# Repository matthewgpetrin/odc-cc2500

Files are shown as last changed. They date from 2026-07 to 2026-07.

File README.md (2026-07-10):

Copyright © 2026 Matthew Petrin

Liscenses are annoying. Please feel free to use this design for any personal projects. Please do not sell any products using this design without my express permission. And of course, follow any local RF regulations.

---
<kbd> 
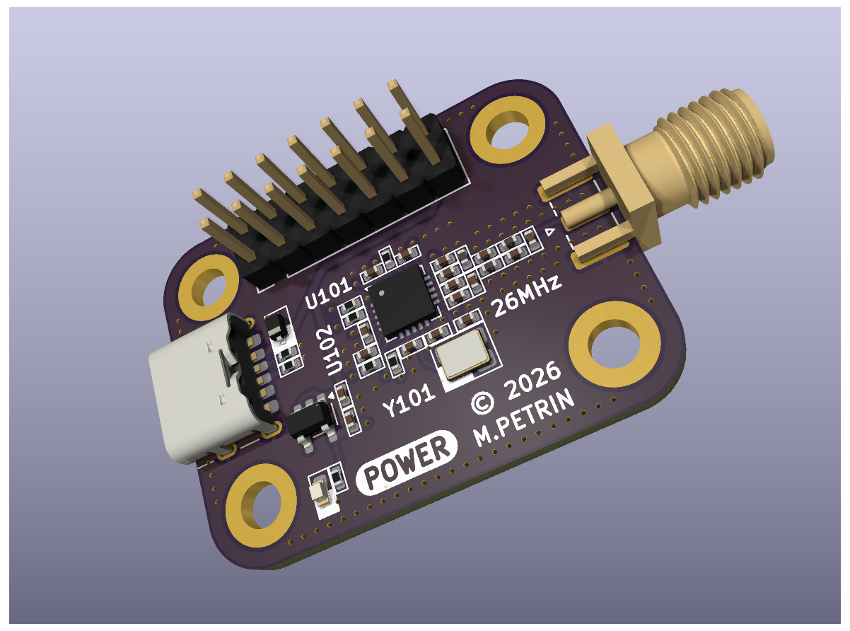
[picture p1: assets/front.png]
	 
</kbd>

---
<kbd> 
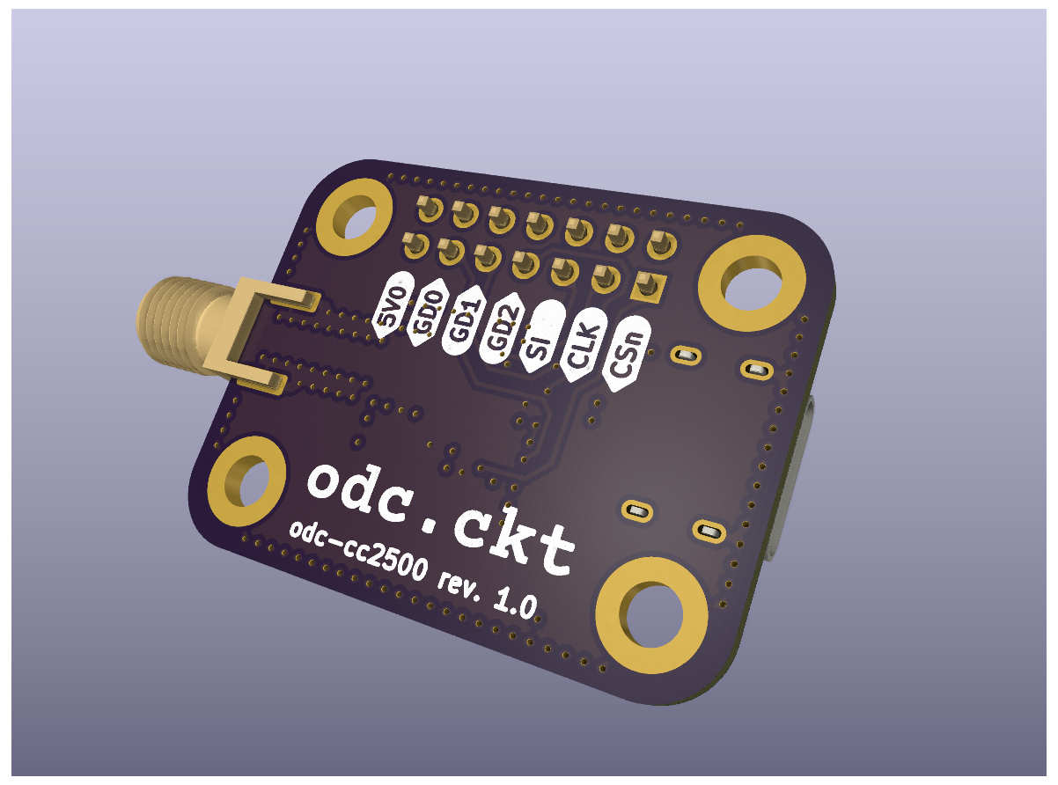
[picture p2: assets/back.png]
	 
</kbd>

## About:
This repo contains KiCAD files and fabrication outputs for a simple breakout board designed around the CC2500 transceiver. The board features a 0.1" pitch header providing access to the IC's control pins, and an SMA header on the RF output.

The board is to be powered by a 5V DC source, which is regulated down to 3.3V. Power can be provided via the rectangular header, or via USB C.

The project is designed in KiCAD 9, and should be compatible with equal or greater versions. All required symbols and footprints are contained within.

## Part Selection:
A BOM is provided in the repo. There are a few components which may be affected by manufacturing processes:

The choice of termination capacitors around the crystal resonator will depend on board parasitics - see the CC2500 datasheet for further details

The choice of current-limiting resistor on the power LED will obviously depend on the forward voltage of the selected LED and the desired brightness.

The series termination resistors on the CC2500 may need to be adjusted/shorted depending on bus impedance, bus length, edge rate, and external capacitance.

## Directories:
`assets`: Images associated with documentation.

`docs`: Currently empty. May be updated in the future.

`fab`: Files required for board fabrication and assembly (bill-of-materials, gerbers, schematics, and position files).

`kicad`: KiCAD project files, including schematic, layout, symbols, footprints, and design rules.

## Other Notes:
Board mounting holes are compatible with m3 or 4-40 screws, and are spaced 26x18 mm.

As of rev. 1.0, the mounting holes are not grounded.

## Datasheets:
[CC2500](https://www.ti.com/lit/ds/symlink/cc2500.pdf?ts=1783648273403&)

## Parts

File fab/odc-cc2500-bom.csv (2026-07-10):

Reference | Qty | Value | Manufacturer | Mfr. PN | Digikey PN | Mouser PN
C101,C102,C103,C110 | 4 | 100n | Murata | GCM155R71H104KE02D | 490-10672-1-ND | 81-GCM155R71H104KE2D
C104,C105,C106 | 3 | 220p | Murata | GRM1555C1H221JA01D | 490-1293-1-ND | 81-GRM1555C1H221JA01
C107,C108 | 2 | 100p | Murata | GRM1555C1H101JA01D | 490-5922-1-ND | 81-GRM1555C1H101JA1D
C109,C111 | 2 | 1.00p | Murata | GRM1555C1H1R0BA01D | 490-6206-1-ND | 81-GRM1555C1H1R0BA1D
C112 | 1 | 1.80p | Murata | GJM1555C1H1R8BB01D | 490-8089-1-ND | 81-GJM1555C1H1R8BB01
C113 | 1 | 1.50p | Murata | GJM1555C1H1R5BB01D | 490-8087-1-ND | 81-GJM1555C1H1R5BB1D
C114,C115 | 2 | 18.0p | Murata | GRM1555C1H180JA01D | 490-5858-1-ND | 81-GRM1555C1H180JA1D
C116,C117 | 2 | 2.20u | Murata | GRM155Z71A225KE44D | 490-GRM155Z71A225KE44DCT-ND | 81-GRM155Z71A225KE4D
D101 | 1 | SDD32A05L01 | YAGEO | SDD32A05L01 | 13-SDD32A05L01CT-ND | 603-SDD32A05L01
D102 | 1 | LED | Rohm | SML-D12M8WT86 | 846-SML-D12M8WT86CT-ND | 755-SML-D12M8WT86
J101 | 1 | SMA | Samtec | SMA-J-P-H-ST-EM1 | SAM8857-ND | 200-SMAJPHSTEM1
J102 | 1 | 0.1" Header | Adam Tech | PH2-14-UA | 2057-PH2-14-UA-ND | 737-PH2-14-UA
J103 | 1 | USBC | Amphenol ICC | 10164359-00011LF | 609-10164359-00011LFCT-ND | 649-10164359-00011LF
L101,L102,L103 | 3 | 1.20n | Murata | LQG15HS1N2B02D | 490-LQG15HS1N2B02DCT-ND | 81-LQG15HS1N2B02D
R101 | 1 | 10.0k | Panasonic | ERJ-2GEJ103X | P10KJCT-ND | 667-ERJ-2GEJ103X
R102,R103,R104 | 3 | 100 | Panasonic | ERJ-2GEJ101X | P100JCT-ND | 667-ERJ-2GEJ101X
R105 | 1 | 56.0k | Panasonic | ERJ-2RKF5602X | P56.0KLCT-ND | 667-ERJ-2RKF5602X
R106 | 1 | 220 | Panasonic | ERJ-2RKF2200X | P220LCT-ND | 667-ERJ-2RKF2200X
R107,R108 | 2 | 5.10k | Panasonic | ERJ-2RKF5101X | P5.10KLCT-ND | 667-ERJ-2RKF5101X
U101 | 1 | CC2500 | Texas Instruments | CC2500RGPR | 296-38562-1-ND | 595-CC2500RGPR
U102 | 1 | TPS7A2033PD | Texas Instruments | TPS7A2033PDBVR | 296-TPS7A2033PDBVRCT-ND | 595-TPS7A2033PDBVR
Y101 | 1 | ABM8-26.000MHZ | Abracon | ABM8-26.000MHz-10-D-1-G-T | 535-15004-1-ND | 815-M826000MHZ10D1GT

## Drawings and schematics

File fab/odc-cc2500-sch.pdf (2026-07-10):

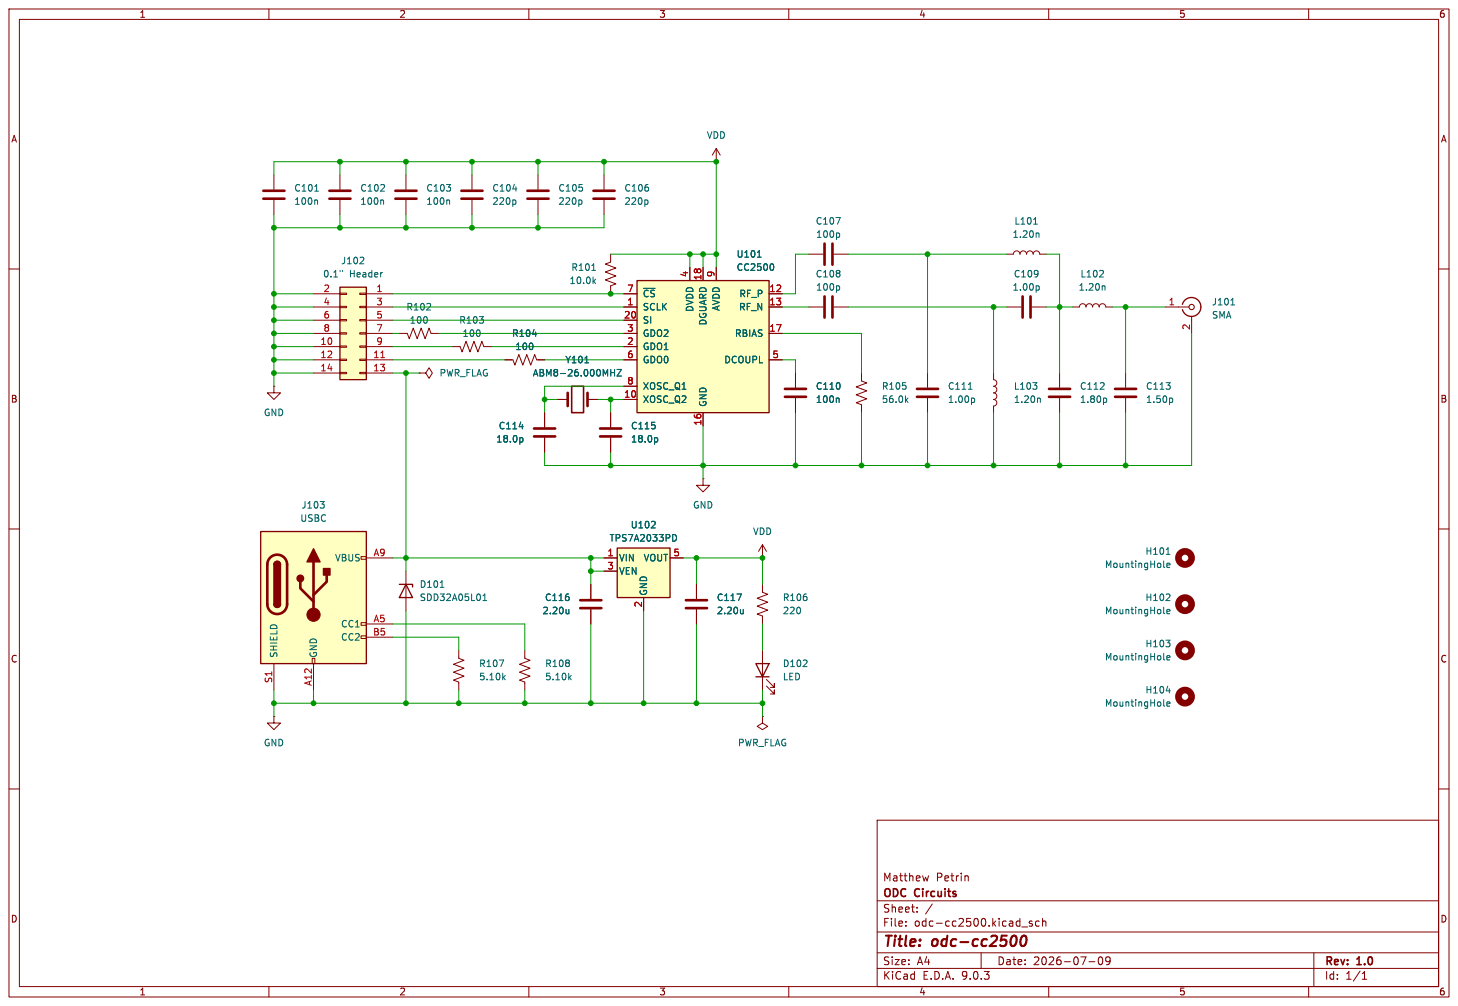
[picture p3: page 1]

File: odc-cc2500.kicad_sch Sheet: / ODC Circuits Matthew Petrin

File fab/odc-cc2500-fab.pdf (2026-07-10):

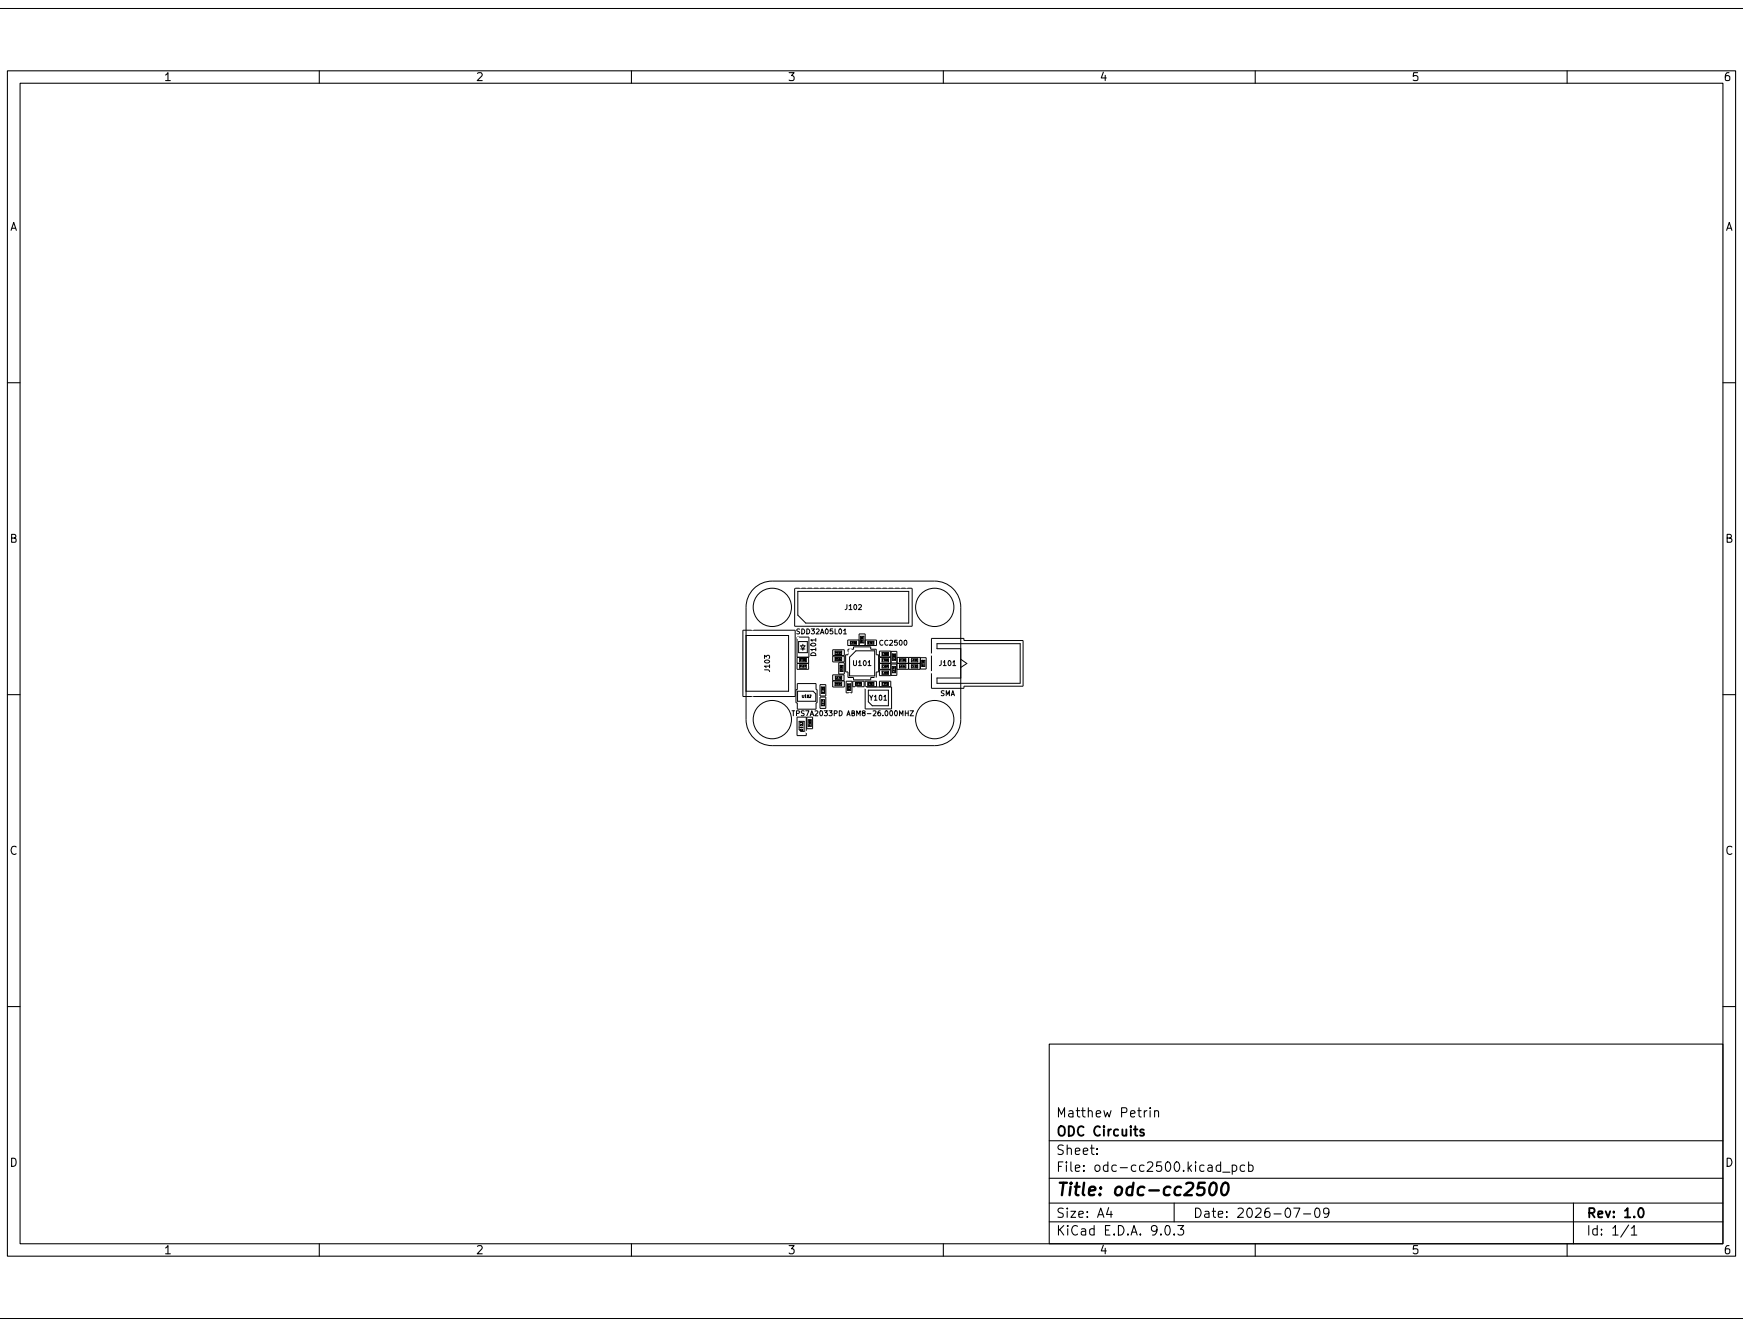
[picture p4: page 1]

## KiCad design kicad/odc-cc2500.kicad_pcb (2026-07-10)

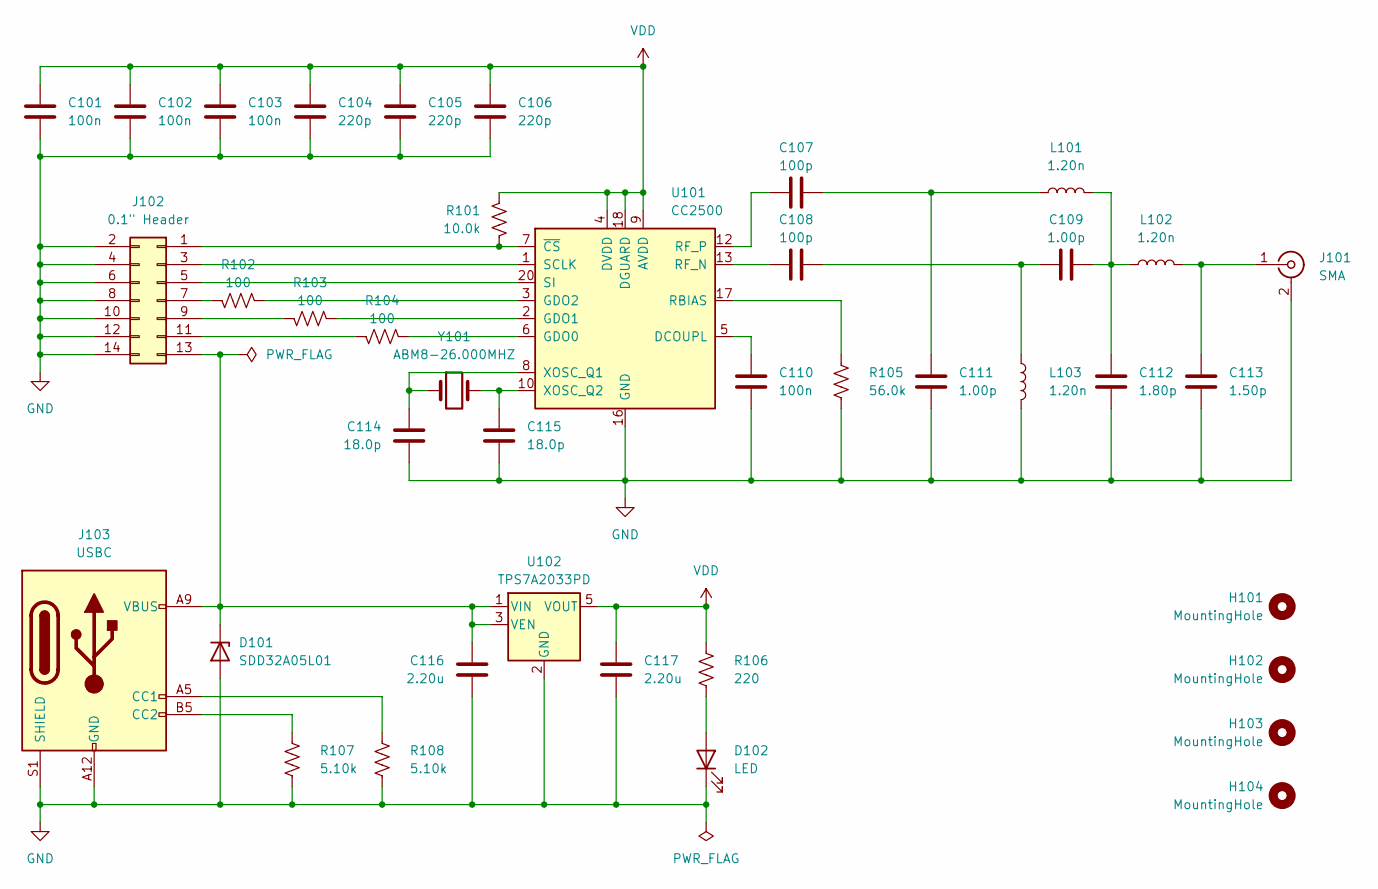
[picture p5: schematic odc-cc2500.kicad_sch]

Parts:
C101, C102, C103, C110: 100n; C_0402_1005Metric; Mfr. PN GCM155R71H104KE02D; Digikey PN 490-10672-1-ND
C104, C105, C106: 220p; C_0402_1005Metric; Mfr. PN GRM1555C1H221JA01D; Digikey PN 490-1293-1-ND
C107, C108: 100p; C_0402_1005Metric; Mfr. PN GRM1555C1H101JA01D; Digikey PN 490-5922-1-ND
C109, C111: 1.00p; C_0402_1005Metric; Mfr. PN GRM1555C1H1R0BA01D; Digikey PN 490-6206-1-ND
C112: 1.80p; C_0402_1005Metric; Mfr. PN GJM1555C1H1R8BB01D; Digikey PN 490-8089-1-ND
C113: 1.50p; C_0402_1005Metric; Mfr. PN GJM1555C1H1R5BB01D; Digikey PN 490-8087-1-ND
C114, C115: 18.0p; C_0402_1005Metric; Mfr. PN GRM1555C1H180JA01D; Digikey PN 490-5858-1-ND
C116, C117: 2.20u; C_0402_1005Metric; Mfr. PN GRM155Z71A225KE44D; Digikey PN 490-GRM155Z71A225KE44DCT-ND
D101: SDD32A05L01; D_SOD-323; Mfr. PN SDD32A05L01; Digikey PN 13-SDD32A05L01CT-ND
D102: LED; LED_0603_1608Metric; Mfr. PN SML-D12M8WT86; Digikey PN 846-SML-D12M8WT86CT-ND
H101, H102, H103, H104: MountingHole; MountingHole_3.2mm_M3_DIN965_Pad
J101: SMA; SMA_Samtec_SMA-J-P-H-ST-EM1_EdgeMount; Mfr. PN SMA-J-P-H-ST-EM1; Digikey PN SAM8857-ND
J102: 0.1" Header; PinHeader_2x07_P2.54mm_Vertical; Mfr. PN PH2-14-UA; Digikey PN 2057-PH2-14-UA-ND
J103: USBC; USB_C_Receptacle_HRO_TYPE-C-31-M-17; Mfr. PN 10164359-00011LF; Digikey PN 609-10164359-00011LFCT-ND
L101, L102, L103: 1.20n; L_0402_1005Metric; Mfr. PN LQG15HS1N2B02D; Digikey PN 490-LQG15HS1N2B02DCT-ND
R101: 10.0k; R_0402_1005Metric; Mfr. PN ERJ-2GEJ103X; Digikey PN P10KJCT-ND
R102, R103, R104: 100; R_0402_1005Metric; Mfr. PN ERJ-2GEJ101X; Digikey PN P100JCT-ND
R105: 56.0k; R_0402_1005Metric; Mfr. PN ERJ-2RKF5602X; Digikey PN P56.0KLCT-ND
R106: 220; R_0402_1005Metric; Mfr. PN ERJ-2RKF2200X; Digikey PN P220LCT-ND
R107, R108: 5.10k; R_0402_1005Metric; Mfr. PN ERJ-2RKF5101X; Digikey PN P5.10KLCT-ND
U101: CC2500; Texas_RGP0020H_VQFN-20-1EP_4x4mm_P0.5mm_EP2.4x2.4mm; Mfr. PN CC2500RGPR; Digikey PN 296-38562-1-ND
U102: TPS7A2033PD; SOT-23-5; Mfr. PN TPS7A2033PDBVR; Digikey PN 296-TPS7A2033PDBVRCT-ND
Y101: ABM8-26.000MHZ; Crystal_SMD_3225-4Pin_3.2x2.5mm; Mfr. PN ABM8-26.000MHz-10-D-1-G-T; Digikey PN 535-15004-1-ND

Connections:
GND: C101.1, C102.1, C103.1, C104.1, C105.1, C106.1, C110.1, C111.1, C112.1, C113.1, C114.1, C115.1, C116.1, C117.1, D101.2 (A), D102.1 (K), J101.2 (Ext), J102.2, J102.4, J102.6, J102.8, J102.10, J102.12, J102.14, J103.A12 (GND), J103.B12 (GND), J103.S1 (SHIELD), L103.1, R105.2, R107.2, R108.2, U101.16 (GND), U101.19 (GND), U101.21 (GND), U102.2 (GND)
unnamed: C107.1, C111.2, L101.2
unnamed: C108.1, C109.2, L103.2
unnamed: C109.1, C112.2, L101.1, L102.2
unnamed: C116.2, D101.1 (K), J102.13, J103.A9 (VBUS), J103.B9 (VBUS), U102.1 (VIN), U102.3 (VEN)
unnamed: D102.2 (A), R106.2
unnamed: C113.2, J101.1 (In), L102.1
unnamed: J102.1, R101.2, U101.7 (~CS)
unnamed: J102.3, U101.1 (SCLK)
unnamed: J102.5, U101.20 (SI)
unnamed: J102.7, R102.2
unnamed: J102.9, R103.2
unnamed: J102.11, R104.2
unnamed: J103.A5 (CC1), R108.1
unnamed: J103.B5 (CC2), R107.1
unnamed: C110.2, U101.5 (DCOUPL)
unnamed: R104.1, U101.6 (GDO0)
unnamed: R103.1, U101.2 (GDO1)
unnamed: R102.1, U101.3 (GDO2)
unnamed: R105.1, U101.17 (RBIAS)
unnamed: C108.2, U101.13 (RF_N)
unnamed: C107.2, U101.12 (RF_P)
unnamed: C114.2, U101.8 (XOSC_Q1), Y101.1
unnamed: C115.2, U101.10 (XOSC_Q2), Y101.3
VDD: C101.2, C102.2, C103.2, C104.2, C105.2, C106.2, C117.2, R101.1, R106.1, U101.4 (DVDD), U101.9 (AVDD), U101.11 (AVDD), U101.14 (AVDD), U101.15 (AVDD), U101.18 (DGUARD), U102.5 (VOUT)

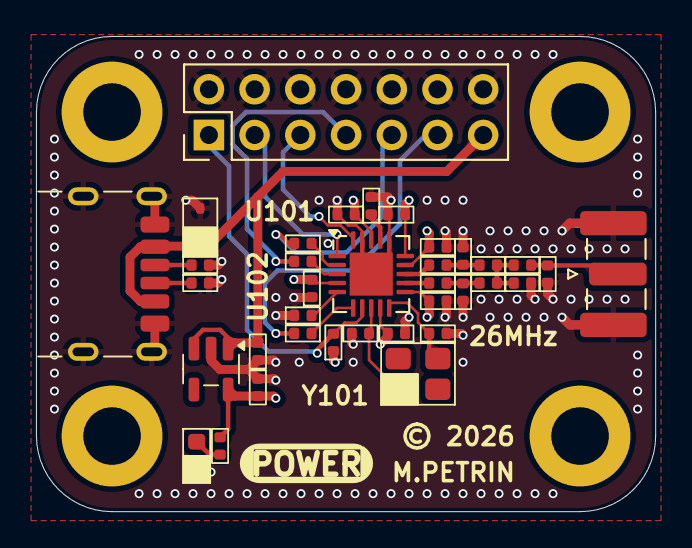
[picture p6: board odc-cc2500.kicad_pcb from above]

Board: 4 copper layers, 34.4 x 26.4 mm, 40 parts (0 on the bottom side), 25 nets.
